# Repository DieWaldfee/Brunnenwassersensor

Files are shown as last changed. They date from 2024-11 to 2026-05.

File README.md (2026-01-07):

# Brunnenwassersensor
to measure groundwater level and temperature

Der Brunnenwassersensor sitzt in einem KG-Rohr DN50 (Abwasserrohr) und misst per Laser die Wasserhöhe, die Wassertemperatur und die Lufttemperatur im Brunnenschacht. Die Konstruktion ist für ein 3.5m langes Brunnenrohr ausgelegt, sodass die normale Grundwasseränderung (Sommer/Winter) wie auch die dynamische Grundwasserabsenkung im Brunnen bei Betrieb einer Brunnenpumpe erfasst werden kann. Übertragen werden die Messdaten via MQTT an einen MQTT-Broker. So kann der Messwert in einer Hausautomation erfasst und dargestellt werden.

Wozu braucht man das: keine Ahnung, aber es geht :-)
Scherz beiseite: Messung der dynamischen Wasserabsenkung bei Einsatz einer Brunnenpumpe, Messung des saisonalen Grundwasserspiegels und dessen Temperatur.

Aufgebaut ist die Elektronik mit einem ESP32, zwei DS18B20 Temperatursensoren und einem Waveshare TOF Laser Sensor B. Der Lasersensor ist besonders, da er eine Laserfokussierung von 1-2° hat - ideal, um im dünnen KG-Rohr DN50 zu messen!
Hier der Link zum Sensor-Datasheet: https://www.waveshare.com/wiki/TOF_Laser_Range_Sensor_(B)
Um den Sensor korrekt zu zentrieren nehmt ihr euer Handy mit dessen Kamera. Die CCDs sehen den Laser - das Auge kann den Laser nicht direkt sehen. => Linse mittig am Ende des Rohres positionieren / halten. Sensor in seiner Halterung ausrichten - fertig.

Im Repository liegen die STL-Dateien, um die Komponenten mit einem 3D-Drucker auszudrucken, der C++-Code für den ESP32, das Eagle-file für das Platinendesign auf Lochrasterkarte (zum Nachlöten) und die Fusiom360-Dateien.

Einrichtung:
Einstellung für euer eingesetzten DS18B20-Sensoren - die haben natürlich andere Adressen...
grafik
Offset-Einstellung zwischen Oberkante Sensor und Oberkante Gelände (GOK):
grafik
...und danach natürlich eure User/Passwörter in der secrets.h:<p>
grafik

viel Spaß beim Nachbauen :-)

### Abhängigkeiten:
OneWire.h:_____________OneWire by Jim Studt, Tom Pollard, Robin James... v2.3.8 (über Arduino IDE)<br>
DallasTemperature.h:___DallasTemperature by Miles Burton v4.0.3 (über Arduino IDE)<br>
WiFi.h:________________Arduino IDE<br>
WiFiClient.h:__________Arduino IDE<br>
PubSubClient.h:________PubSubClient by Nick O'Leary v2.8 (über Arduino IDE) [also tested with PubSubClient3 V3.2.1]<br>
Wire.h:________________by Jim Studt, Tom Pollard, Robiun James... v2.3.8 (über Arduino IDE)<br>
esp_task_wdt.h:________Espressif IDE<br>

### verwendete IDE
Im Verzeichnis `ESP23_Dev_Kit_V4` liegen die Arduino-files. Im Verzeichnis `vscode` liegt der gleiche Inhalt für VSCode. Zukünftig wird im VSCode weiter entwickelt. Wenn die Parallelität zu aufwändig wird nehme ich die Arduino IDE aus dem Repository. Solange das *.ino-file im Repository liegt wird es auch aktuell gehalten.

### Board ESP32
esp32 by Espressif Systems v1.0.6 (über Arduino IDE)<br>
Getestet habe ich auch v2.0.5<br>

grafik

Ausgabe im serial Monitor unter debug=1:
grafik

so sieht das bei mir im ioBroker (...oder wo auch immer ihr das weiterverwenden wollt :-)) aus:
grafik

Hier die Platine:




Aufbau des Sonsorrohrs:






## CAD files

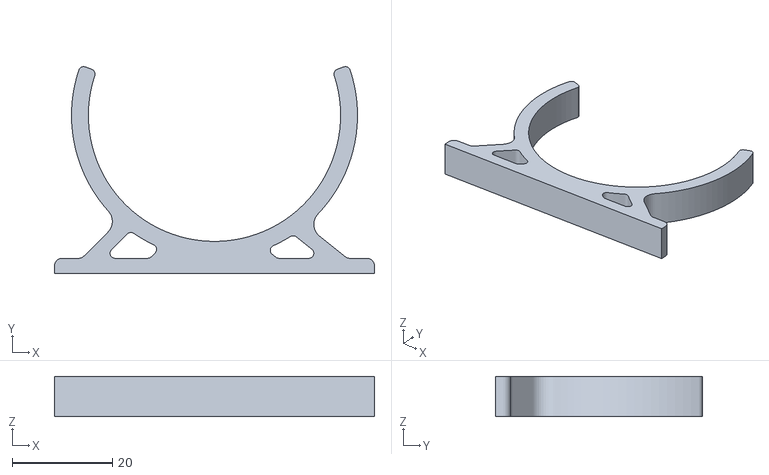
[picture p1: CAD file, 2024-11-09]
STL/Anstandsklemme v2.stl
63.8 x 41.2 x 8.00

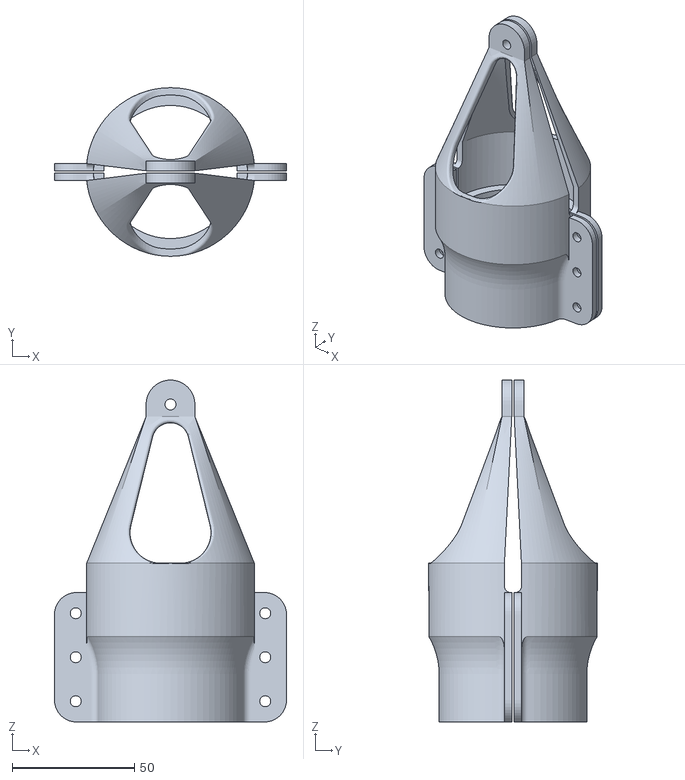
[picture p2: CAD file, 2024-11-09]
STL/Halter v10.stl
95.0 x 69.0 x 140.0

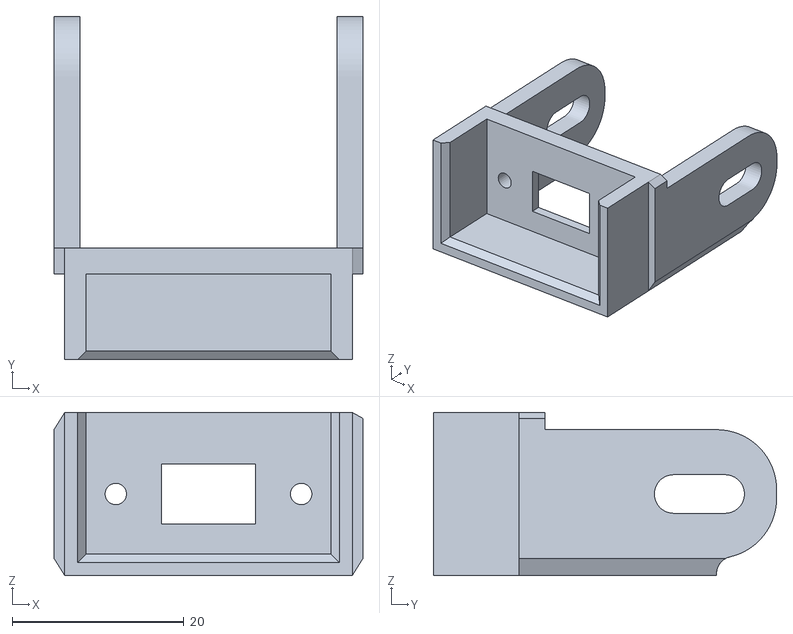
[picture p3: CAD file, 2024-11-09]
STL/Sensorhalter v8.stl
36.0 x 40.0 x 19.0

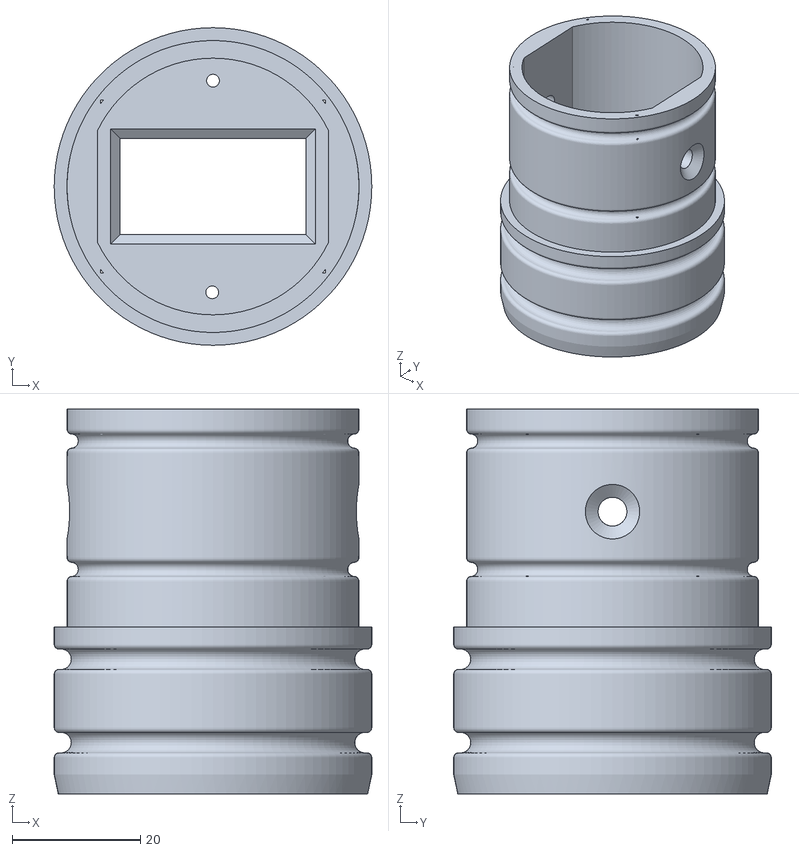
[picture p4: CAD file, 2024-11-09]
STL/Gehäuse_unten v17.stl
49.5 x 49.5 x 60.0

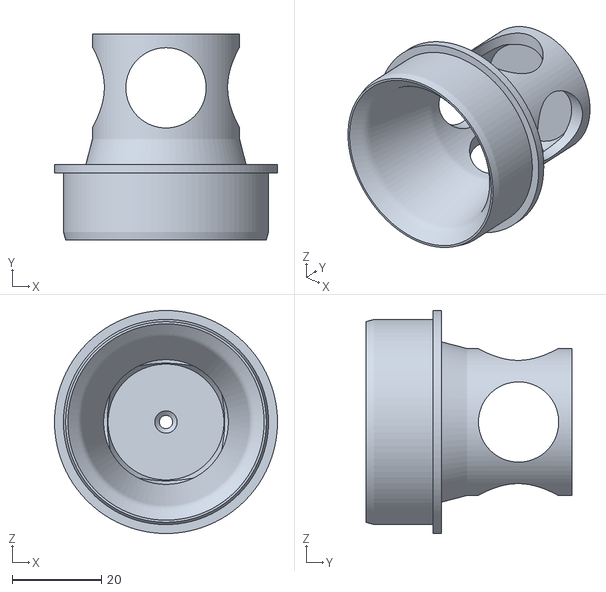
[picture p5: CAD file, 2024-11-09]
STL/Abschlussstopfen v3.stl
50.0 x 46.3 x 50.0

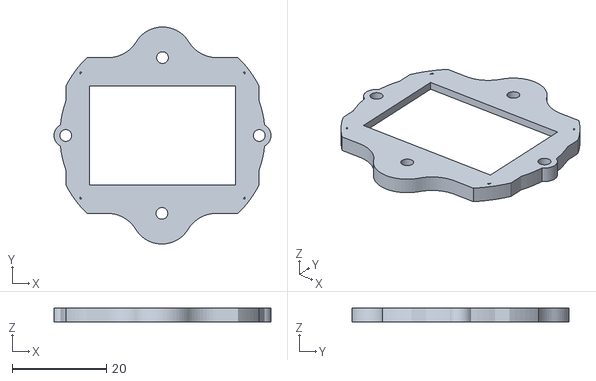
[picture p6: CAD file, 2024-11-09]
STL/Glasträger v4.stl
46.0 x 46.0 x 3.00

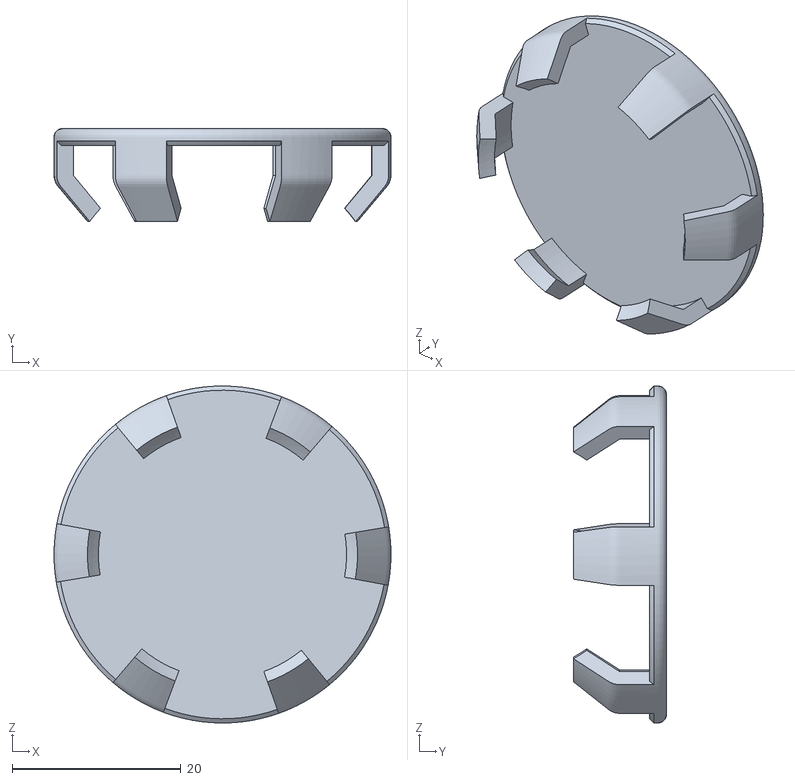
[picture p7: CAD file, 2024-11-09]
STL/Reflektor v1.stl
40.0 x 11.0 x 40.0

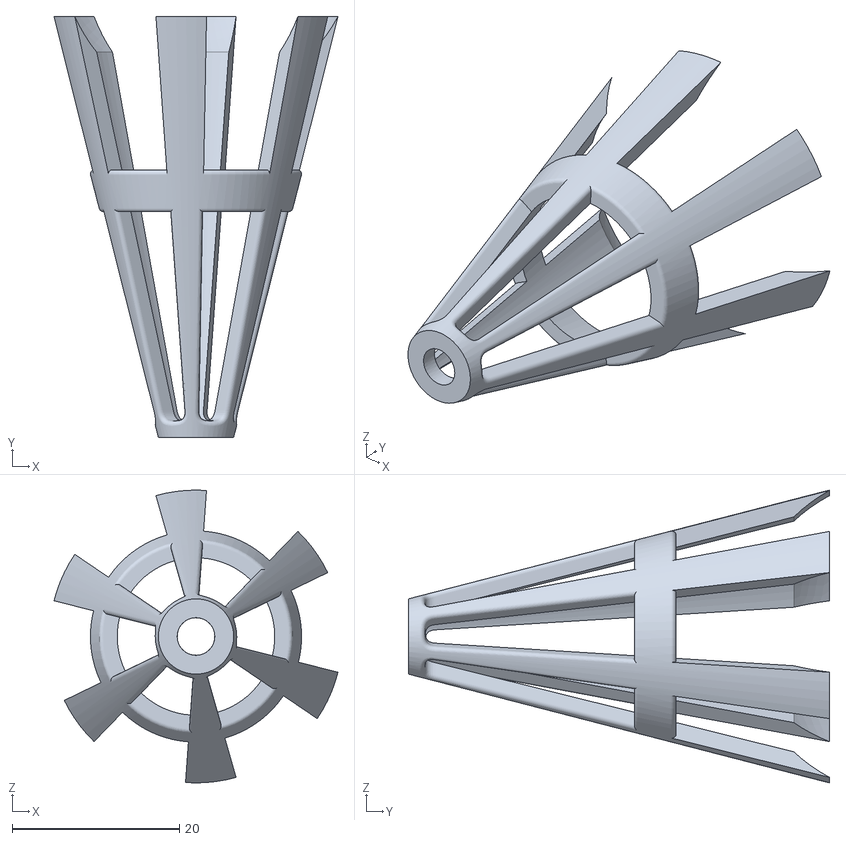
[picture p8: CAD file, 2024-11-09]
STL/Reflektor_Lot v2.stl
33.9 x 50.3 x 35.0

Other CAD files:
Fusion360/Abschlussstopfen v2.f3d
Fusion360/Anstandsklemme v2.f3d
Fusion360/Gehäuse_unten v17.f3d
Fusion360/Glasträger v5.f3d
Fusion360/Halter v10.f3d
Fusion360/KG ROhr DN50x500 mod v2.f3d
Fusion360/KG ROhr DN50x500 v2.f3d
Fusion360/Reflektor v1.f3d
Fusion360/Reflektor_Lot v2.f3d
Fusion360/Sensor v2.f3d
Fusion360/Sensorhalter v8.f3d
Fusion360/Stopfen DN50 mod v2.f3d
Fusion360/Stopfen DN50 v1.f3d
Fusion360/Zusammenbau v16.f3z

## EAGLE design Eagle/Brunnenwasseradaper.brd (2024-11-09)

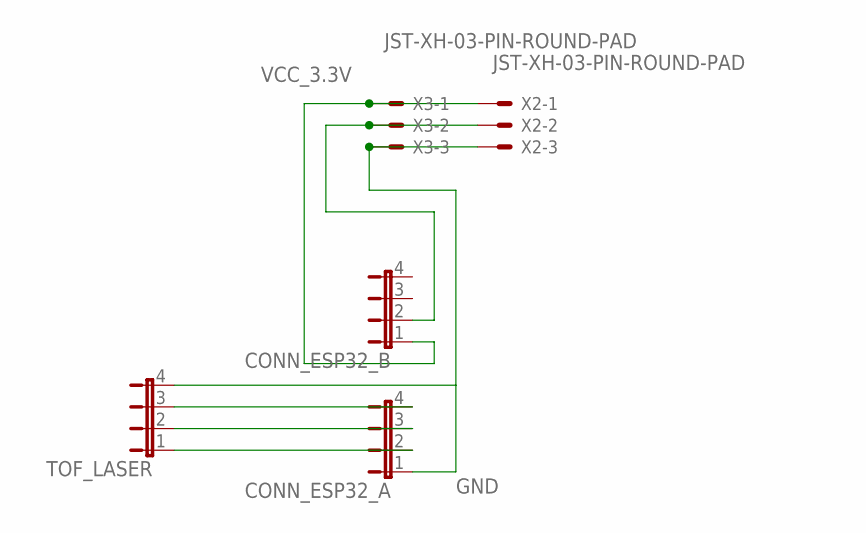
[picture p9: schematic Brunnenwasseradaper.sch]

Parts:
CONN_ESP32_A, CONN_ESP32_B: JP4E; JP4
TOF_LASER: JP4E; JP4
X2, X3: JST-XH-03-PIN-ROUND-PAD; JST-XH-03-PACKAGE-ROUND-PAD

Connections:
GND: CONN_ESP32_A.1, TOF_LASER.4, X2.3, X3.3
unnamed: CONN_ESP32_A.3, TOF_LASER.2
unnamed: CONN_ESP32_A.4, TOF_LASER.3
unnamed: CONN_ESP32_A.2, TOF_LASER.1
unnamed: CONN_ESP32_B.2, X2.2, X3.2
VCC_3.3V: CONN_ESP32_B.1, X2.1, X3.1

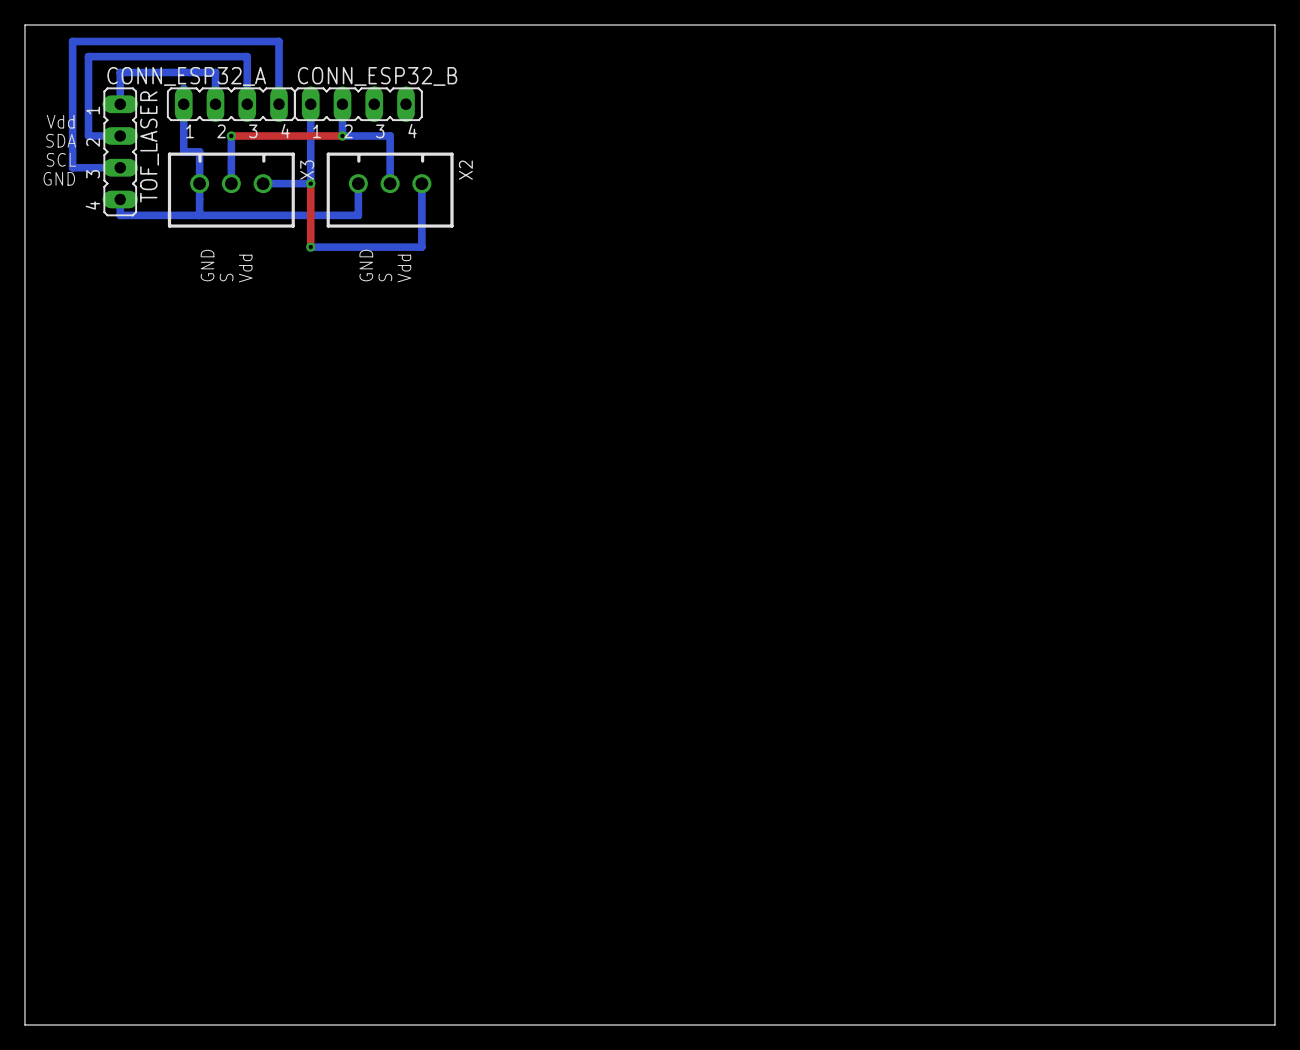
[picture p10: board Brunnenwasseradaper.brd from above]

Board: 2 copper layers, 100.0 x 80.0 mm, 5 parts (0 on the bottom side), 6 nets.

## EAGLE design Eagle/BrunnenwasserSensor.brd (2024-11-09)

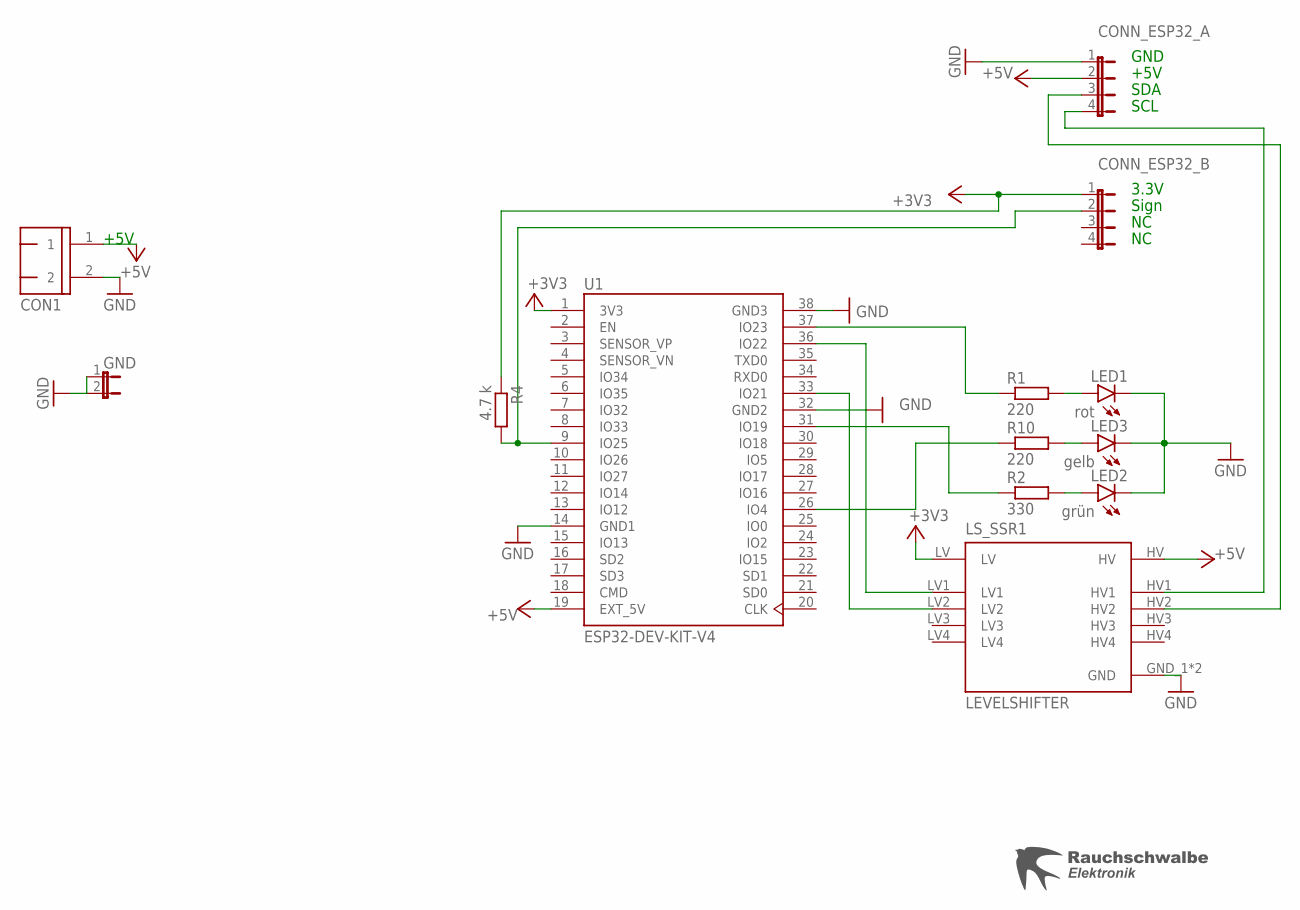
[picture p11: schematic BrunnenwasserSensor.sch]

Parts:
CON1: WAGO-500-2
CONN_ESP32_A, CONN_ESP32_B: JP4E; JP4
GND: JP1E; JP1
LED1: rot; LED3MM
LED2: grün; LED3MM
LED3: gelb; LED3MM
LS_SSR1: LEVELSHIFTER
R1, R10: 220; 0207/10
R2: 330; 0207/10
R4: 4.7 k; 0207/10
U1: ESP32-DEV-KIT-V4
U$1: LOGO_RAUCHSCHWALBE

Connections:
+3V3: CONN_ESP32_B.1, LS_SSR1.LV, R4.1, U1.1 (3V3)
+5V: CON1.1, CONN_ESP32_A.2, LS_SSR1.HV, U1.19 (EXT_5V)
GND: CON1.2, CONN_ESP32_A.1, GND.1, GND.2, LED1.K (C), LED2.K (C), LED3.K (C), LS_SSR1.GND_1 (GND), LS_SSR1.GND_2 (GND), U1.14 (GND1), U1.32 (GND2), U1.38 (GND3)
unnamed: R1.1, U1.37 (IO23)
unnamed: LED3.A, R10.2
unnamed: R2.1, U1.31 (IO19)
unnamed: LED1.A, R1.2
unnamed: LED2.A, R2.2
unnamed: CONN_ESP32_B.2, R4.2, U1.9 (IO25)
unnamed: R10.1, U1.26 (IO4)
SCL: LS_SSR1.LV1, U1.36 (IO22)
SCL2: CONN_ESP32_A.4, LS_SSR1.HV1
SDA: LS_SSR1.LV2, U1.33 (IO21)
SDA2: CONN_ESP32_A.3, LS_SSR1.HV2

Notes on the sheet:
+5V
GND
SDA
SCL
3.3V
Sign

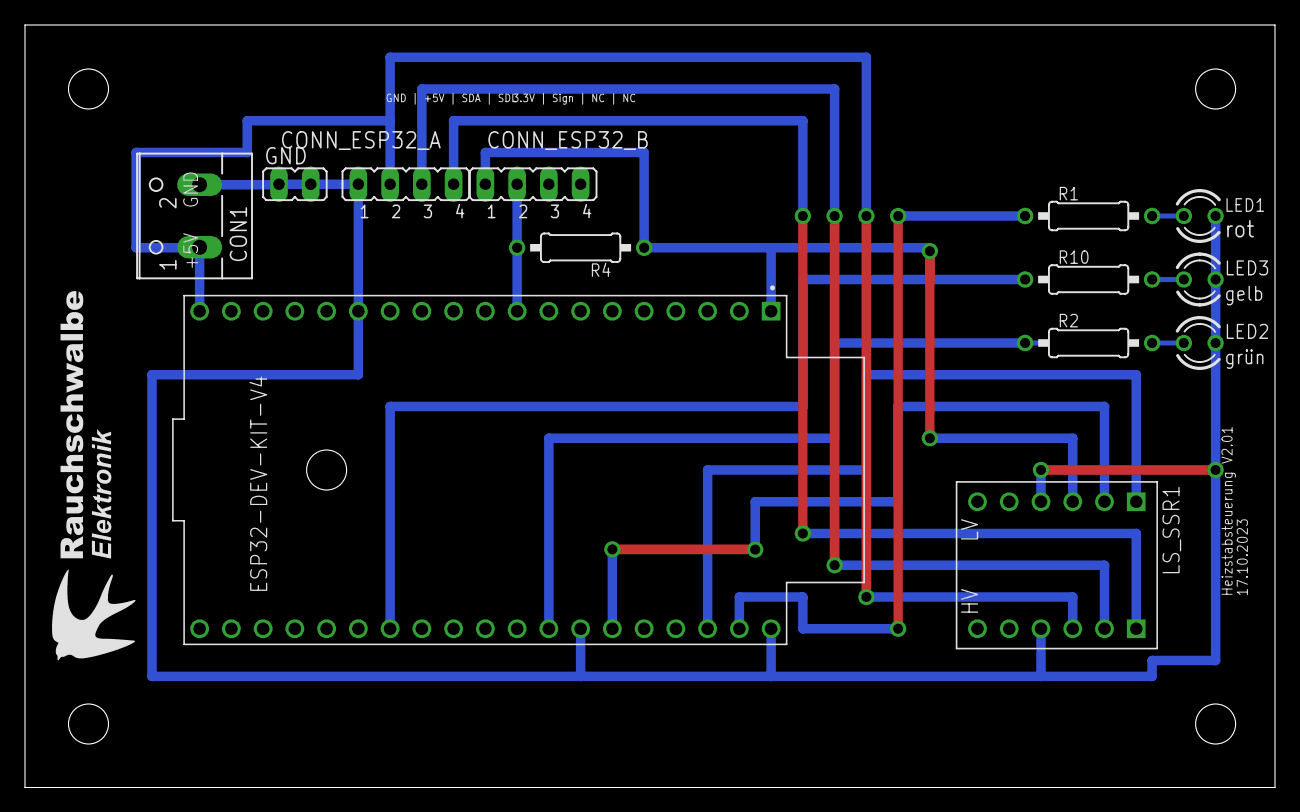
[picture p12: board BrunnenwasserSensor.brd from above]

Board: 2 copper layers, 100.0 x 61.0 mm, 14 parts (0 on the bottom side), 14 nets.

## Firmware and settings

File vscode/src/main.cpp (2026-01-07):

//https://beelogger.de/sensoren/temperatursensor-ds18b20/ für Pinning und Anregung
#include <OneWire.h>
#include <DallasTemperature.h>
#include <WiFi.h>
#include <WiFiClient.h>
#include <PubSubClient.h>
#include <Wire.h>
#include <esp_task_wdt.h>
#include "secrets.h"

#define LED_ERROR 23                     // Pin für die Fehler-LED
#define LED_MSG 4                        // Pin für die Botschafts-LED (blinkt bei übertragener Botschft über MQTT)
#define LED_OK 19                        // Pin für die OK-LED
#define ONE_WIRE_BUS 25                  // Pin für die OneWire-Verbindung du den Temperatursensoren
static byte debug = 0;
static String lastError = "";

//Verbindung zum TOF-Sensor via i2c (Standard-Adresse 0x52)
#define I2C_ADDRESS 0x08                 // Default I2C address of the sensor
#define SDA_PIN 21                       // Pin für das SDA-Signal
#define SCL_PIN 22                       // Pin für das SCL-Signal
#define GOK_OFFSET 2.50                  // Distanz zwischen GOK (GeländeOberKante) und Messsystem 0-Punkt [m]
uint16_t volatile distance = 0;          // Distanz gemessen mit TOF-Sensor zur Oberkante des Schwimmers [mm]
bool volatile disStatus = 0;             // Status der Distanzmessung: 0=Fehlmessung; 1=ok
uint8_t volatile presicion = 0;          // Präzision der Messung [mm]
float volatile groundwaterLevel = 0.0;   // Grundwasserspiegel: grounwaterlevel = distance + GOK_OFFSET

// Definition der Zugangsdaten WiFi
WiFiClient myWiFiClient;

//Definition der Zugangsdaten MQTT
#define MQTT_CLIENTID "ESP32_Brunnenwassersensor" //Name muss eineindeutig auf dem MQTT-Broker sein!
uint16_t MQTT_keepAlive = 90;                     // KeepAlive Zeit in Sekunden für die MQTT-Verbindung
#define MQTT_SOCKETTIMEOUT 30
#define MQTT_SERIAL_PUBLISH_STATUS "SmartHome/Garten/ESP32_Brunnenwassersensor/status"
#define MQTT_SERIAL_RECEIVER_COMMAND "SmartHome/Garten/ESP32_Brunnenwassersensor/command"
#define MQTT_SERIAL_PUBLISH_DS18B20 "SmartHome/Garten/ESP32_Brunnenwassersensor/Temperatur/"
#define MQTT_SERIAL_PUBLISH_WATER "SmartHome/Garten/ESP32_Brunnenwassersensor/Wasserhöhe/"
#define MQTT_SERIAL_PUBLISH_STATE "SmartHome/Garten/ESP32_Brunnenwassersensor/state/"
#define MQTT_SERIAL_PUBLISH_CONFIG "SmartHome/Garten/ESP32_Brunnenwassersensor/config/"
#define MQTT_SERIAL_PUBLISH_BASIS "SmartHome/Garten/ESP32_Brunnenwassersensor/"
DeviceAddress myDS18B20Address;
String Adresse;
unsigned long MQTTReconnect = 0;
#define MQTT_QUEUEDEPTH 50                // Tiefe der MQTT-Queue - 50 Botschaften
#define MQTT_QUEUEMAXWAITTIME 3           // Wartezeit für das Senden in eine Queue - danach Error!
#define QUEUEMAXWAITTIME 3                // Wartezeit für das Senden in eine Queue - danach Error!
struct MqttJob {                          // Struktur der MQTT-Queue
  char topic[128];                        // topic:   Topic auf den die Botschaft gesendet werden soll -> 180 Zeichen lang
  char payload[256];                      // payload: Botschaft, die an das Topic gesendet werden soll. -> 256 Zeichen max.
  bool retain;                            // retain:  true, wenn die Botschaft im Broker gespeichert bleibt und false, wenn
};                                        // nur die angemeldeten User die Botschaft erhalten - diese dann vergessen wird.
PubSubClient mqttClient(myWiFiClient);
static QueueHandle_t mqttQueue;           // Queuedefinition für die MQTT-Queue
static TaskHandle_t hmqtt;                // handler für den MQTT-Sender-Task

// Anzahl der angeschlossenen DS18B20 - Sensoren
int DS18B20_Count = 0; //Anzahl der erkannten DS18B20-Sensoren
//Beispiel Sensorsetting (Ausgabe im Debugmodus (debug = 1) auf dem serial Monitor)
  //LastError: nicht spezifizierter Temperatursensor gefunden! Reboot! (Adresse: 0x28, 0xd4, 0x28, 0x43, 0xd4, 0x25, 0x6a, 0x0a)
float volatile tempWater = 0.0;   //Sensor in Slot 1
float volatile tempAir = 0.0;     //Sensor in Slot 2
const char* AdresseWater = "0x28, 0xd4, 0x28, 0x43, 0xd4, 0x25, 0x6a, 0x0a"; // Wassertemperatur - Adresee kann über den Debugmodus (debug = 1) ermittelt werden aus dem serial Monitor
const char* AdresseAir = "0x28, 0x9b, 0xa2, 0x57, 0x04, 0xe1, 0x3c, 0x8b";   // Lufttemperatur - Adresee kann über den Debugmodus (debug = 1) ermittelt werden aus dem serial Monitor
float DS18B20_minValue = -55.0;   //unterster Messwert im Messbereich [°C]
float DS18B20_maxValue = 125.0;   //unterster Messwert im Messbereich [°C]
#define DS18B20_RESOLUTION 12     // 9bit: +-0.5°C @ 93.75 ms; 10bit: +-0.25°C @ 187.5 ms; 11bit: +-0.125°C @ 375 ms; 12bit: +-0.0625°C @ 750 ms
#define DS18B20_DELAY 752         // Wartezeit nach angetriggerter Messung [ms]
int tempTSensorFail = 0;          // Anzahl der aktuell hintereinanderfolgenden Fehler beim Auslesen der Temp-Sensoren
int maxTSensorFail = 3;           // 3 gestattete Fehler in Folge beim Auslesen der Temperatursensoren

//Initialisiere OneWire und Thermosensor(en)
OneWire oneWire(ONE_WIRE_BUS);
DallasTemperature myDS18B20(&oneWire);

//Mutexdefinitionen
static SemaphoreHandle_t mutexTemp;
static SemaphoreHandle_t mutexTOF;
static SemaphoreHandle_t mutexTempSensor;
static SemaphoreHandle_t mutexTOFSensor;

//TaskRefrechTime
#define MQTTStateRefresh 60000         // Alle 60.000 Ticks = 60sec
#define DistanceRefresh 30000          // Alle 30.000 Ticks = 30sec

//TaskHandler zur Verwendung mit ESP watchdog
static TaskHandle_t htempSensor;
static TaskHandle_t htofSensor;
static TaskHandle_t hMQTTwatchdog;

//erforderliche Funtions-Prototypen
bool mqttPublishQueue(const char*, const char*, bool);

//-------------------------------------
// Basisfunktion zum sicheren Reset
void safeReset() {
  // MQTT disconnecten
  Serial.println("MQTT Disconnect...");
  if (mqttClient.connected()) mqttClient.disconnect();
  delay(50);
  // TCP-Puffer flushen - alle Pakete aus dem Speicher
  Serial.println("Flush TCP-Buffer...");
  myWiFiClient.flush();
  delay(50);
  // restart durchführen
  Serial.println("ESP32 Reset!");
  ESP.restart();
}

//-------------------------------------
// Callback für MQTT
void mqttCallback(char* topic, byte* message, unsigned int length) {
  String mqttTopic;
  String mqttPayload;
  BaseType_t rc;
  String str;
  unsigned long mqttValue;
  String mqttMessage;
  String mqttTopicAC;
  byte tx_ac = 1;
  for (int i = 0; i < length; i++)
  {
    str += (char)message[i];
  }
  if (debug > 1) {
    Serial.print("Nachricht aus dem Topic: ");
    Serial.print(topic);
    Serial.print(". Nachricht: ");
    Serial.println(str);
  }
  //Test-Botschaften  
  mqttTopicAC = MQTT_SERIAL_PUBLISH_BASIS;
  mqttTopicAC += "ac";
  if (str.startsWith("Test")) {
    if (debug) Serial.println("Test -> Test OK");
    mqttPublishQueue(mqttTopicAC.c_str(), "Test OK", false);
    tx_ac = 0;
  }

  //debug-Modfikation  
  if ((tx_ac) && (str.startsWith("debug=0"))) {
    debug = 0;
    mqttPublishQueue(mqttTopicAC.c_str(), "debug=0 umgesetzt", false);
    tx_ac = 0;
  }
  if ((tx_ac) && (str.startsWith("debug=1"))) {
    debug = 1;
    mqttPublishQueue(mqttTopicAC.c_str(), "debug=1 umgesetzt", false);
    tx_ac = 0;
  }
  if ((tx_ac) && (str.startsWith("debug=2"))) {
    debug = 2;
    mqttPublishQueue(mqttTopicAC.c_str(), "debug=2 umgesetzt", false);
    tx_ac = 0;
  }
  if ((tx_ac) && (str.startsWith("debug=3"))) {
    debug = 3;
    mqttPublishQueue(mqttTopicAC.c_str(), "debug=3 umgesetzt", false);
    tx_ac = 0;
  }
  //ErrorLED aus
    if ((tx_ac) && (str.startsWith("ErrorLED aus"))) {
    mqttMessage = "ErrorLED ausgeschaltet";
    digitalWrite(LED_ERROR, LOW);
    if (debug > 2) Serial.println(mqttMessage);
    mqttPublishQueue(mqttTopicAC.c_str(), mqttMessage.c_str(), false);
    tx_ac = 0;
  }
  if ((tx_ac) && (str.startsWith("restart"))) {
    mqttPublishQueue(mqttTopicAC.c_str(), "reboot in einer Sekunde!", false);
    if (debug) Serial.println("für Restart: alles aus & restart in 1s!");
    digitalWrite(LED_OK, LOW);
    digitalWrite(LED_ERROR, HIGH);
    vTaskDelay(1000);
    if (debug) Serial.println("führe Restart aus!");
    safeReset();
  }
  if ((tx_ac) && (str.startsWith("reboot"))) {
    mqttPublishQueue(mqttTopicAC.c_str(), "reboot in einer Sekunde!", false);
    if (debug) Serial.println("für Restart: alles aus & restart in 1s!");
    digitalWrite(LED_OK, LOW);
    digitalWrite(LED_ERROR, HIGH);
    vTaskDelay(1000);
    if (debug) Serial.println("führe Restart aus!");
    safeReset();
  }
}

//-------------------------------------
//Subfunktionen für MQTT-Status-Task
// MQTT DS18B20 Status senden
void printDS18B20MQTT() {
  String mqttTopic;
  String mqttJson;
  String mqttPayload;
  int i;
  for (i = 0; i < DS18B20_Count; i++) {
    //MQTT-Botschaften
    //JSON        
    myDS18B20.getAddress(myDS18B20Address,i);
    Adresse="";
    for (uint8_t j = 0; j < 8; j++)
    {
      Adresse += "0x";
      if (myDS18B20Address[j] < 0x10) Adresse += "0";
      Adresse += String(myDS18B20Address[j], HEX);
      if (j < 7) Adresse += ", ";
    }
    mqttTopic = MQTT_SERIAL_PUBLISH_DS18B20 + String(i) + "/JSON"; 
    mqttJson = "{\"ID\":\"" + String(i) + "\"";
    mqttJson += ",\"Temperatur\":\"" + String(myDS18B20.getTempCByIndex(i)) + "\"";
    mqttJson += ",\"Adresse\":\"(" + Adresse + ")\"";
    if (Adresse == AdresseWater) mqttJson += ",\"Ort\":\"Temperatur Wasser\"}";
    if (Adresse == AdresseAir) mqttJson += ",\"Ort\":\"Temperatur Luft\"}";
    if (debug > 2) Serial.println("MQTT_JSON: " + mqttJson);
    mqttPublishQueue(mqttTopic.c_str(), mqttJson.c_str(),false);
    //Temperatur
    mqttTopic = MQTT_SERIAL_PUBLISH_DS18B20 + String(i) + "/Temperatur";
    mqttPayload = String(myDS18B20.getTempCByIndex(i));
    mqttPublishQueue(mqttTopic.c_str(), mqttPayload.c_str(),false);
    if (debug > 2) Serial.print("MQTT ID: ");
    if (debug > 2) Serial.println(mqttPayload);
    //ID
    mqttTopic = MQTT_SERIAL_PUBLISH_DS18B20 + String(i) + "/ID";
    mqttPayload = String(i);
    mqttPublishQueue(mqttTopic.c_str(), mqttPayload.c_str(),false);
    if (debug > 2) Serial.print("MQTT Temperatur: ");
    if (debug > 2) Serial.println(mqttPayload);
    //Adresse
    mqttTopic = MQTT_SERIAL_PUBLISH_DS18B20 + String(i) + "/Adresse";
    mqttPublishQueue(mqttTopic.c_str(), Adresse.c_str(),false);
    if (debug > 2) Serial.print("MQTT Adresse: ");
    if (debug > 2) Serial.println(Adresse);
    //Ort
    mqttTopic = MQTT_SERIAL_PUBLISH_DS18B20 + String(i) + "/Ort";
    if (Adresse == AdresseWater) mqttPayload = "Temperatur Wasser";
    if (Adresse == AdresseAir) mqttPayload = "Temperatur Luft";
    mqttPublishQueue(mqttTopic.c_str(), mqttPayload.c_str(),false);
    if (debug > 2) Serial.print("MQTT Ort: ");
    if (debug > 2) Serial.println(mqttPayload);
  }
}
// MQTT Wasserhöhe / Distanz Status senden
void printGroundwaterLevelMQTT() {
  String mqttTopic;
  String mqttJson;
  String mqttPayload;
  if (groundwaterLevel != 0) {
    //Grundwasserspiegel
    mqttTopic = MQTT_SERIAL_PUBLISH_WATER + String("Grundwasserspiegel_unter_GOK");
    mqttPayload = groundwaterLevel;
    mqttPublishQueue(mqttTopic.c_str(), mqttPayload.c_str(),false);
    if (debug > 2) Serial.print("Grundwasserspiegel unter GOK: ");
    if (debug > 2) Serial.println(mqttPayload);
  }
}
// MQTT Status Betrieb senden
void printStateMQTT() {
  String mqttTopic;
  String mqttJson;
  String mqttPayload;
  mqttTopic = MQTT_SERIAL_PUBLISH_STATE;
  mqttTopic += "JSON";
  mqttJson = "{\"WiFi_Signal_Strength\":\"" + String(WiFi.RSSI()) + "\"";
  mqttJson += ",\"WiFi_IP_Adress\":\"" + WiFi.localIP().toString() + "\"";
  mqttJson += ",\"WiFi_MAC_Adress\":\"" + WiFi.macAddress() + "\"";
  mqttJson += ",\"lastError\":\"" + String(lastError) + "\"}";
  if (debug > 2) Serial.println("MQTT_JSON: " + mqttJson);
  mqttPublishQueue(mqttTopic.c_str(), mqttJson.c_str(),false);
  //lastError
  if (lastError != ""){
    mqttTopic = MQTT_SERIAL_PUBLISH_STATE;
    mqttTopic += "lastError";
    mqttPayload = lastError;
    mqttPublishQueue(mqttTopic.c_str(), mqttPayload.c_str(),false);
    if (debug > 2) Serial.print("LastError: ");
    if (debug > 2) Serial.println(mqttPayload);
  }
  //WiFi Signalstärke
  mqttTopic = MQTT_SERIAL_PUBLISH_STATE;
  mqttTopic += "WiFi_Signal_Strength";
  mqttPayload = WiFi.RSSI();
  mqttPublishQueue(mqttTopic.c_str(), mqttPayload.c_str(),false);
  if (debug > 2) Serial.print("WiFi Signalstärke: ");
  if (debug > 2) Serial.println(mqttPayload);
  //WiFi IP-Adresse
  mqttTopic = MQTT_SERIAL_PUBLISH_STATE;
  mqttTopic += "WiFi_IP_Adress";
  mqttPayload = WiFi.localIP().toString();
  mqttPublishQueue(mqttTopic.c_str(), mqttPayload.c_str(),false);
  if (debug > 2) Serial.print("WiFi IP-Adresse: ");
  if (debug > 2) Serial.println(mqttPayload);
  //WiFi MAC-Adresse
  mqttTopic = MQTT_SERIAL_PUBLISH_STATE;
  mqttTopic += "WiFi_MAC_Adress";
  mqttPayload = WiFi.macAddress();
  mqttPublishQueue(mqttTopic.c_str(), mqttPayload.c_str(),false);
  if (debug > 2) Serial.print("WiFi MAC-Adresse: ");
  if (debug > 2) Serial.println(mqttPayload);
  //Distanz gemessen
  mqttTopic = MQTT_SERIAL_PUBLISH_STATE;
  mqttTopic += "Distanz_gemessen";
  mqttPayload = distance;
  mqttPublishQueue(mqttTopic.c_str(), mqttPayload.c_str(),false);
  if (debug > 2) Serial.print("Distanz gemessen: ");
  if (debug > 2) Serial.println(mqttPayload);
  //Distanz gemessen [mm]
  mqttTopic = MQTT_SERIAL_PUBLISH_STATE;
  mqttTopic += "Distanz_gemessen";
  mqttPayload = distance;
  mqttPublishQueue(mqttTopic.c_str(), mqttPayload.c_str(),false);
  if (debug > 2) Serial.print("Distanz gemessen [mm]: ");
  if (debug > 2) Serial.println(mqttPayload);
  //Distanz Status
  mqttTopic = MQTT_SERIAL_PUBLISH_STATE;
  mqttTopic += "Distanz_Status";
  if (disStatus == 0) {
    mqttPayload = true;
  } else {
    mqttPayload = false;
  }
  mqttPublishQueue(mqttTopic.c_str(), mqttPayload.c_str(),false);
  if (debug > 2) Serial.print("Distanz Status: ");
  if (debug > 2) Serial.println(mqttPayload);
  //Präzision gemessen [mm]
  mqttTopic = MQTT_SERIAL_PUBLISH_STATE;
  mqttTopic += "Präzision_Distanz";
  mqttPayload = presicion;
  mqttPublishQueue(mqttTopic.c_str(), mqttPayload.c_str(),false);
  if (debug > 2) Serial.print("Präzision Distanz [mm]: ");
  if (debug > 2) Serial.println(mqttPayload);
}
// MQTT Config und Parameter senden
void printConfigMQTT() {
  String mqttTopic;
  String mqttJson;
  //Teil 1
  mqttTopic = MQTT_SERIAL_PUBLISH_CONFIG;
  mqttTopic += "JSON_0";
  mqttJson = "{\"GOK_Offset\":\"" + String(GOK_OFFSET) + "\"}";
  if (debug > 2) Serial.println("MQTT_JSON: " + mqttJson);
  mqttPublishQueue(mqttTopic.c_str(), mqttJson.c_str(),false);
}
//LED-Blik-OK
void LEDblinkMSG(){
  digitalWrite(LED_MSG, HIGH);
  delay(150);
  digitalWrite(LED_MSG, LOW);
}
//-------------------------------------
//MQTT-Status-Task
static void MQTTstate (void *args){
  BaseType_t rc;
  float a1;
  float a2;
  float a3;
  float p1on;
  float p2on;
  float p3on;
  TickType_t ticktime;

  //ticktime initialisieren
  ticktime = xTaskGetTickCount();

  for (;;){                        // Dauerschleife des Tasks
    //Lesen der Temperaturen
    if (debug > 1) Serial.print("TickTime: ");
    if (debug > 1) Serial.print(ticktime);
    if (debug > 1) Serial.println(" | MQTT-Status-Task gestartet");
    if (mqttClient.connected()) {
      rc = xSemaphoreTake(mutexTempSensor, portMAX_DELAY);
      assert(rc == pdPASS);
        rc = xSemaphoreTake(mutexTemp, portMAX_DELAY);
        assert(rc == pdPASS);
          printDS18B20MQTT();
        rc = xSemaphoreGive(mutexTemp);
        assert(rc == pdPASS);
      rc = xSemaphoreGive(mutexTempSensor);
      assert(rc == pdPASS);

      rc = xSemaphoreTake(mutexTOFSensor, portMAX_DELAY);
      assert(rc == pdPASS);
        rc = xSemaphoreTake(mutexTOF, portMAX_DELAY);
        assert(rc == pdPASS);
          printGroundwaterLevelMQTT();
        rc = xSemaphoreGive(mutexTOF);
        assert(rc == pdPASS);
      rc = xSemaphoreGive(mutexTOFSensor);
      assert(rc == pdPASS);

      printStateMQTT();

      printConfigMQTT();
    }

    // Task schlafen legen - restart MQTTStateRefresh ticks
    LEDblinkMSG();
    vTaskDelayUntil(&ticktime, MQTTStateRefresh);
  }
}

//-------------------------------------
//Subfunktionen für MQTTwatchdog-Task
// MQTT Verbindung herstellen (wird auch von setup verwendet!)
void mqttConnect () {
  int i = 0;
  Serial.print("Verbindungsaubfau zu MQTT Server ");
  Serial.print(MQTT_SERVER);
  Serial.print(" Port ");  
  Serial.print(MQTT_PORT);
  Serial.print(" wird aufgebaut ");  
  while (!mqttClient.connected()) {
    Serial.print(".");
    if (mqttClient.connect(MQTT_CLIENTID, MQTT_USER, MQTT_PASSWORD, MQTT_SERIAL_PUBLISH_STATUS, 0, true, "false")) {
      mqttClient.publish(MQTT_SERIAL_PUBLISH_STATUS, "true", true);
      Serial.println("");
      Serial.print("MQTT verbunden!");
    } 
    else {
      if (++i > 20) {
        Serial.println("MQTT scheint nicht mehr erreichbar! Reboot!!");
        safeReset();
      }
      Serial.print("fehlgeschlagen rc=");
      Serial.print(mqttClient.state());
      Serial.println(" erneuter Versuch in 5 Sekunden.");
      delay(5000);      
    }    
  }
  mqttClient.subscribe(MQTT_SERIAL_RECEIVER_COMMAND);
}
// MQTT Verbindungsprüfung 
void checkMQTTconnetion() {
  String mqttTopic;
  String mqttPayload;
  BaseType_t rc;
  if (!mqttClient.connected()) {
    if (debug) Serial.println("MQTT Server Verbindung verloren...");
    if (debug) Serial.print("Disconnect Errorcode: ");
    if (debug) Serial.println(mqttClient.state());  
    //Vorbereitung errorcode MQTT (https://pubsubclient.knolleary.net/api#state)
    mqttTopic = MQTT_SERIAL_PUBLISH_BASIS + String("error");
    mqttPayload = String(String(++MQTTReconnect) + ". reconnect: ") + String("; MQTT disconnect rc=" + String(mqttClient.state()));
    // 0	MQTT_CONNECTED	        Erfolgreich verbunden.
    // 1	MQTT_CONNECTION_TIMEOUT	Verbindung zum Broker hat zu lange gedauert (Timeout).
    // 2	MQTT_CONNECTION_LOST	  Verbindung ging verloren (nach dem Connect).
    // 3	MQTT_CONNECT_FAILED	    Verbindung konnte nicht hergestellt werden (Socket fehlerhaft).
    // 4	MQTT_DISCONNECTED	      Client ist aktuell nicht verbunden.
    // 5	MQTT_CONNECTED_FAILED	  Broker hat die Verbindung abgelehnt (z. B. Authentifizierung)
    //reconnect
    mqttConnect();
    //sende Fehlerstatus
    mqttPublishQueue(mqttTopic.c_str(), mqttPayload.c_str(),false);
    //reconnect zurückmelden
    mqttTopic = MQTT_SERIAL_PUBLISH_BASIS + String("ac");
    mqttPayload = String("MQTT reconnect durchgeführt!");
    mqttPublishQueue(mqttTopic.c_str(),mqttPayload.c_str(),false);
  }
  mqttClient.loop();
}
//-------------------------------------
//MQTT-MQTTwatchdog-Task
static void MQTTwatchdog (void *args){
  BaseType_t rc;
  esp_err_t er;
  TickType_t ticktime;

  //ticktime initialisieren
  ticktime = xTaskGetTickCount();

  er = esp_task_wdt_add(NULL);   // Task zur Überwachung hinzugefügt  
  assert(er == ESP_OK); 

  for (;;){                        // Dauerschleife des Tasks
    // Watchdog zurücksetzen
    esp_task_wdt_reset();
    //Lesen der Temperaturen
    if (debug > 1) Serial.print("TickTime: ");
    if (debug > 1) Serial.print(ticktime);
    if (debug > 1) Serial.println(" | MQTTonlinePrüf-Task gestartet");
    checkMQTTconnetion();

    // Task schlafen legen - restart alle 2s = 2*1000 ticks = 2000 ticks
    // mit mqttClient.loop() wird auch der MQTTcallback ausgeführt!
    vTaskDelayUntil(&ticktime, 2000);
  }
}

//-------------------------------------
//MQTT-MQTTSender-Task
static void mqttSender (void *args){
  MqttJob job;
  BaseType_t rc;
  esp_err_t er;
  TickType_t ticktime;

  //ticktime initialisieren
  ticktime = xTaskGetTickCount();

  for (;;){                        // Dauerschleife des Tasks
    //Statusausgabe
    if (debug > 1) Serial.print("TickTime: ");
    if (debug > 1) Serial.print(ticktime);
    if (debug > 1) Serial.println(" | MQTT-Sender-Task gestartet");
    if (mqttClient.connected()) {
      // Sendebereit -> MQTT-Queue kann geleert werden
      while (xQueuePeek(mqttQueue, &job, 0) == pdPASS) {
        if (mqttClient.connected()) {
          rc = xQueueReceive(mqttQueue, &job, 0) == pdPASS;
          mqttClient.publish(job.topic, job.payload, job.retain);
          if (debug > 2) Serial.print("Topic: ");
          if (debug > 2) Serial.println(job.topic);
          if (debug > 2) Serial.print("Payload: ");
          if (debug > 2) Serial.println(job.payload);
          if (debug > 2) Serial.print("retain: ");
          if (debug > 2) Serial.println(job.retain);
          mqttClient.loop();  // Keepalive
        }
      }    
    }    
    // Task schlafen legen - restart alle 0.5s = 0.5*1000 ticks = 500 ticks
    // mit mqttClient.loop() wird auch der MQTTcallback ausgeführt!
    vTaskDelayUntil(&ticktime, 500);
  }
}
//MQTT-Queue befüllen
bool mqttPublishQueue(const char* topic, const char* payload, bool retain = false) {
  MqttJob job;
  strncpy(job.topic, topic, sizeof(job.topic) - 1);           // Absicherung gegen Buffer-Overflow
  strncpy(job.payload, payload, sizeof(job.payload) - 1);     // Absicherung gegen Buffer-Overflow
  job.retain = retain;
  return xQueueSend(mqttQueue, &job, QUEUEMAXWAITTIME) == pdPASS;
}
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
void loop() {
  //loop wird als Task nicht gebraucht
  vTaskDelete(nullptr);
}

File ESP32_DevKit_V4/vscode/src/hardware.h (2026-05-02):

// hardware.h
#pragma once

// ╔═══════════════════════════════════════════════════════════════════════════╗
// ║  KALIBRIERUNGSWERTE                                                       ║
// ║  Nach Sensorwechsel oder Neukalibrierung anpassen.                        ║
// ╚═══════════════════════════════════════════════════════════════════════════╝

// ─── DS18B20-Sensoradressen ───────────────────────────────────────────────────
// Adresse per Debug-Modus (debug=1) auf dem Serial Monitor ermitteln:
//   DS18B20[n]: <Temp> °C (<Adresse>)
// DS18B20_ADDR_WATER: Sensor im Brunnen unter Wasser – Wassertemperatur
// DS18B20_ADDR_AIR:   Sensor oberhalb des Wasserspiegels – Lufttemperatur
#define DS18B20_ADDR_WATER "0x28, 0xd4, 0x28, 0x43, 0xd4, 0x25, 0x6a, 0x0a"
#define DS18B20_ADDR_AIR   "0x28, 0x9b, 0xa2, 0x57, 0x04, 0xe1, 0x3c, 0x8b"

// ─── TOF-Sensor: Installationsoffset ─────────────────────────────────────────
// Distanz zwischen GOK (GeländeOberKante) und dem mechanischen 0-Punkt des
// Messsystems (Montageposition des TOF-Sensors) [m].
// Nach Einbau/Umbau neu vermessen und anpassen.
#define GOK_OFFSET 2.50

// ╔════════════════════════════════════════════════════════════════════════════╗
// ║  Pinning und Hardwareconfig                                                ║
// ║  DO NOT MODIFY UNLESS YOU KNOW WHAT YOU ARE DOING                         ║
// ╚════════════════════════════════════════════════════════════════════════════╝

// ─── GPIO-Pinbelegung ─────────────────────────────────────────────────────────
#define LED_ERROR    23
#define LED_MSG       4
#define LED_OK       19
#define ONE_WIRE_BUS 25

// ─── TOF-Sensor via I2C ───────────────────────────────────────────────────────
#define I2C_ADDRESS    0x08  // I2C-Adresse des TOF-Sensors (Werkseinstellung)
#define SDA_PIN        21
#define SCL_PIN        22
#define TOF_BOOT_DELAY 50    // Wartezeit nach Power-Up bis Sensor bereit [ms]

// ─── DS18B20-Sensor-Konfiguration ─────────────────────────────────────────────
// 9 bit: ±0,5 °C / 93,75 ms  | 10 bit: ±0,25 °C / 187,5 ms
// 11 bit: ±0,125 °C / 375 ms | 12 bit: ±0,0625 °C / 750 ms
#define DS18B20_RESOLUTION 12
#define DS18B20_DELAY     752  // Wartezeit nach getriggerter Messung [ms]
